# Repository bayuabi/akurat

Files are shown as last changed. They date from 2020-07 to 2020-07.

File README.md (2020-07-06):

# AKURAT
AKURAT stands for "Alat Ukur Kadar Air Tanah", an IoT based soil moisture sensor with ESP-32 inside. This project dedicated for soil
moisture data logging and then collected data can be analyzed for research purpose.

### Specifications :
- Wi-Fi based IoT
- OLED Display
- Solar panel energy harvesting
- 3500 mAh Lithium Ion battery
- Deep sleep enabled (for long time battery life)

### Further Specifications :
- LoRa/NB-IoT IoT protocols

Reach me on email (bayuabi31@gmail.com) for more informations.

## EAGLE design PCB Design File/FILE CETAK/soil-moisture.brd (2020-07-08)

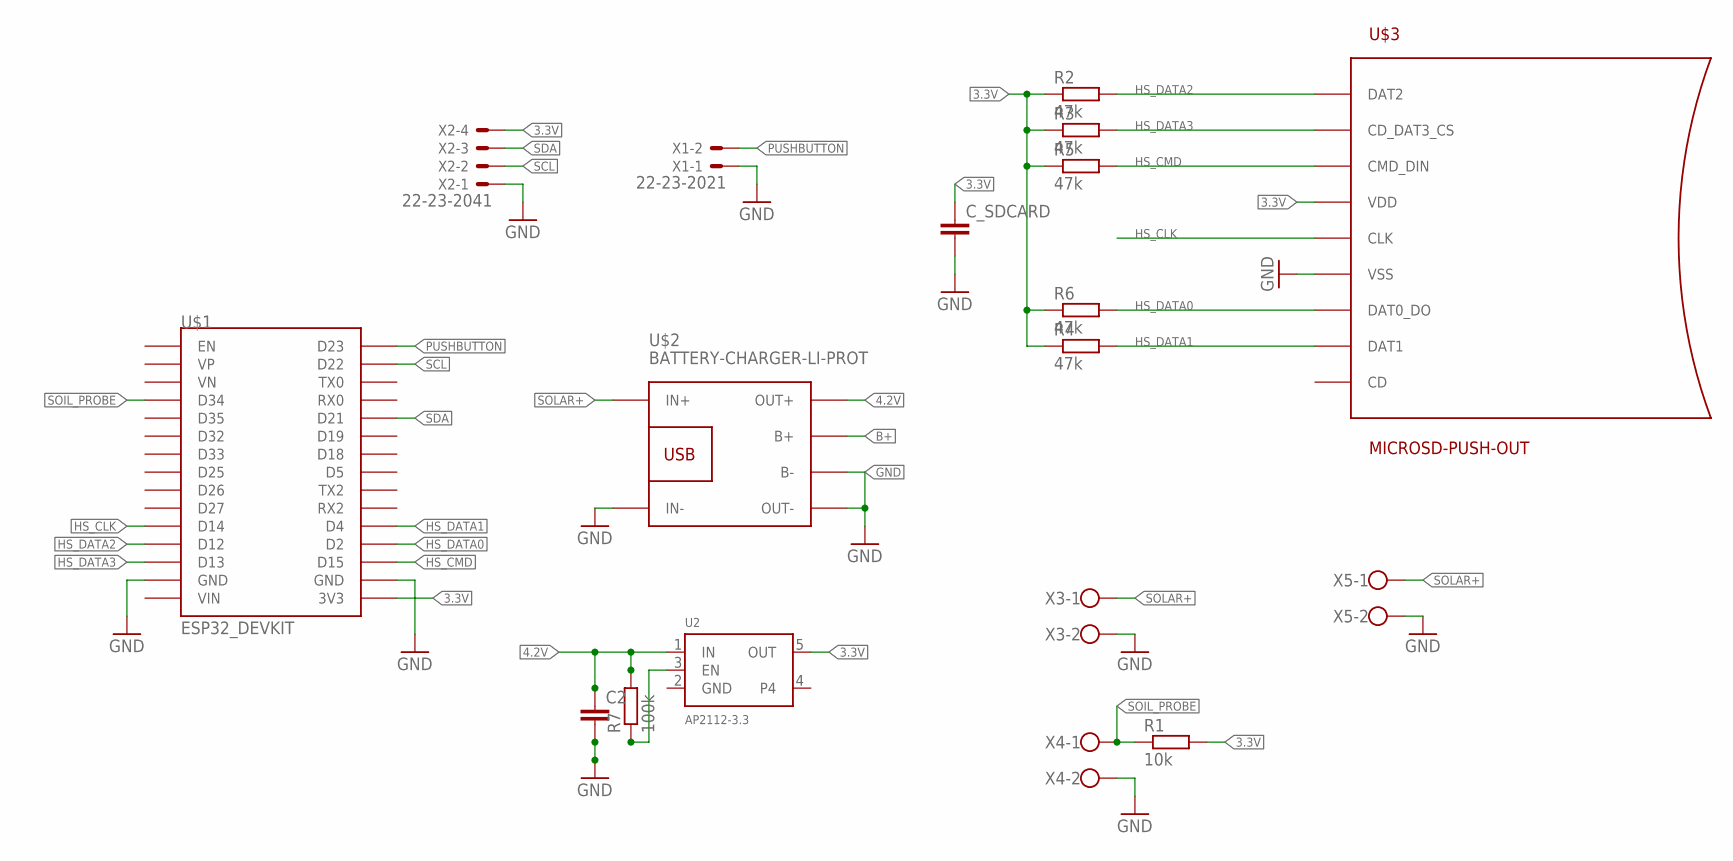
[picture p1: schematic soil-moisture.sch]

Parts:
C2: C-EUC0805; C0805
C_SDCARD: C-EUC0805; C0805
R1: 10k; R0805
R2, R3, R4, R5, R6: 47k; R0805
R7: 100k; R0805
U2: AP2112-3.3; SOT23-5
U$1: ESP32_DEVKIT
U$2: BATTERY-CHARGER-LI-PROT
U$3: MICROSD-PUSH-OUT
X1: 22-23-2021
X2: 22-23-2041
X3, X4, X5: W237-102

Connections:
3.3V: C_SDCARD.1, R1.2, R2.1, R3.1, R4.1, R5.1, R6.1, U2.5 (OUT), U$1.3V3, U$3.4 (VDD), X2.4
4.2V: C2.1, R7.2, U2.1 (IN), U$2.OUT+
B+: U$2.B+
GND: C2.2, C_SDCARD.2, U2.2 (GND), U$1.GND@1 (GND), U$1.GND@2 (GND), U$2.B-, U$2.IN-, U$2.OUT-, U$3.6 (VSS), U$3.G1 (VSS), U$3.G2 (VSS), U$3.G3 (VSS), U$3.G4 (VSS), X1.1, X2.1, X3.2, X4.2, X5.2
HS_CLK: U$1.D14, U$3.5 (CLK)
HS_CMD: R5.2, U$1.D15, U$3.3 (CMD_DIN)
HS_DATA0: R6.2, U$1.D2, U$3.7 (DAT0_DO)
HS_DATA1: R4.2, U$1.D4, U$3.8 (DAT1)
HS_DATA2: R2.2, U$1.D12, U$3.1 (DAT2)
HS_DATA3: R3.2, U$1.D13, U$3.2 (CD_DAT3_CS)
unnamed: R7.1, U2.3 (EN)
PUSHBUTTON: U$1.D23, X1.2
SCL: U$1.D22, X2.2
SDA: U$1.D21, X2.3
SOIL_PROBE: R1.1, U$1.D34, X4.1
SOLAR+: U$2.IN+, X3.1, X5.1

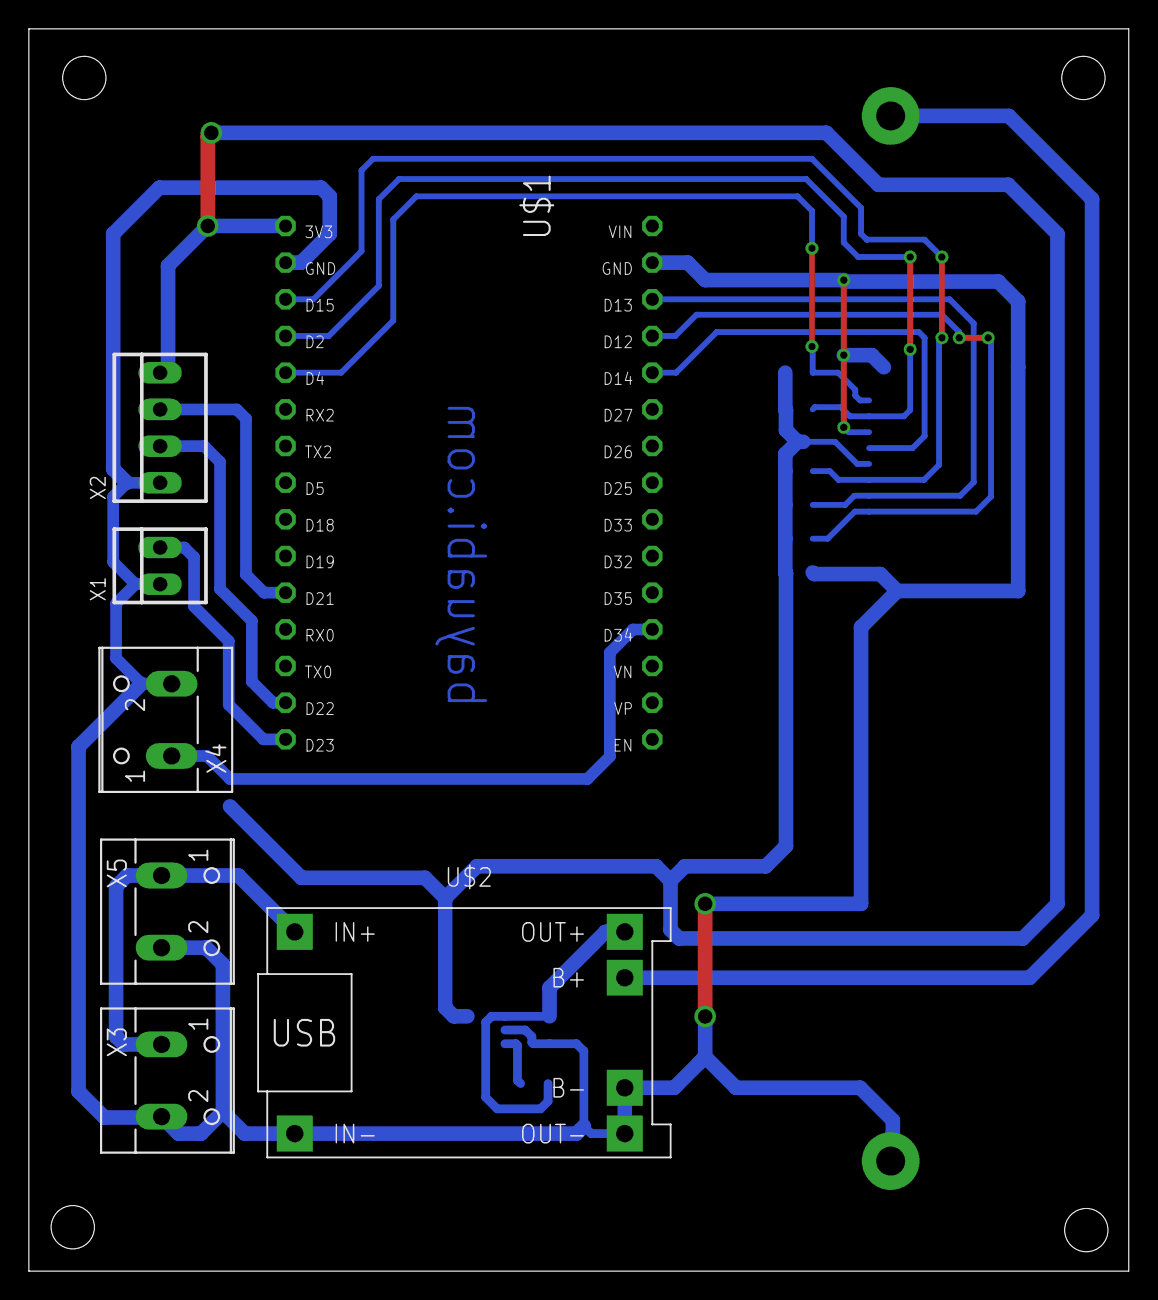
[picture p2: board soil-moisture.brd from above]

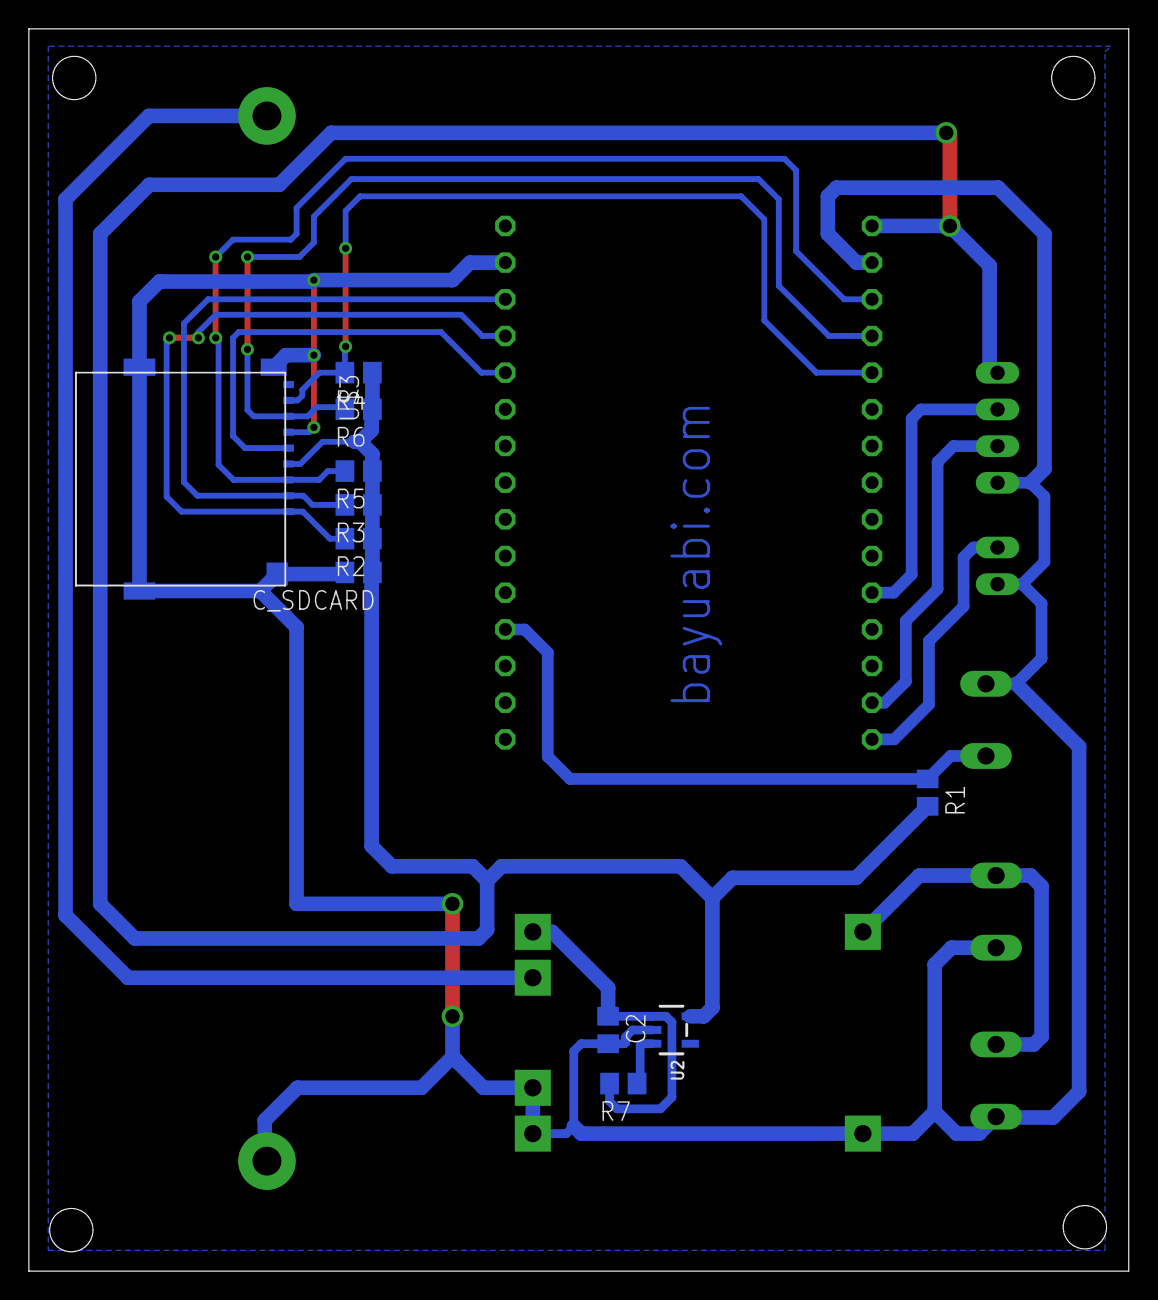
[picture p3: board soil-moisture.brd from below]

Board: 2 copper layers, 76.2 x 86.0 mm, 18 parts (11 on the bottom side), 15 nets.

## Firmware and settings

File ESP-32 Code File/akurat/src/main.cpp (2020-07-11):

#include <Arduino.h>
#include <WiFi.h>
#include <HTTPClient.h>
#include <WiFiClient.h>
#include <ESP_WiFiManager.h>
#include <Wire.h>
#include <Adafruit_GFX.h>
#include <Adafruit_SSD1306.h>

#define DEBUG true

#define SCREEN_WIDTH 128 
#define SCREEN_HEIGHT 64 

#define OLED_RESET     -1 
Adafruit_SSD1306 display(SCREEN_WIDTH, SCREEN_HEIGHT, &Wire, OLED_RESET);

String WIFI_SSID = "";
String WIFI_PASSWORD = "";

String MAIN_URL = "http://172.20.10.8/";
String SUBFOLDER_URL = "iot-dashboard/inputdata.php";

String CHIP_ID = "";

const char * API_KEY_TABLE[10] = {
                                  "miq3TdbIZP",
                                  "FDuzbCgPPb",
                                  "NqqRDCN52d",
                                  "QFsMgCkZsL",
                                  "lUpmcjKMeP",
                                  "F10NJIbkPf",
                                  "a1HQ8Gz6lM",
                                  "jPD9rmW5z4",
                                  "2vIt0XlQIQ",
                                  "ZoUBAoZ2uF"
                                 };

#define PUSHBUTTON_PIN  23
#define SOIL_PROBE_PIN  34

unsigned long startTime;
const uint16_t WIFIMANAGER_WAIT_TIME = 3000;
bool wifiSetting = false;

bool wifiInit(uint8_t timeout);
String getChipId();
bool sendData(int data);

void setup() {
  Serial.begin(115200);

  pinMode(PUSHBUTTON_PIN, INPUT_PULLUP);
  pinMode(SOIL_PROBE_PIN, INPUT);

  ESP_WiFiManager ESP_wifiManager("AutoConnectAP");
  ESP_wifiManager.setDebugOutput(true);
  ESP_wifiManager.setAPStaticIPConfig(IPAddress(192, 168, 100, 1), IPAddress(192, 168, 100, 1), IPAddress(255, 255, 255, 0));
  ESP_wifiManager.setMinimumSignalQuality(-1);
  ESP_wifiManager.setSTAStaticIPConfig(IPAddress(192, 168, 2, 114), IPAddress(192, 168, 2, 1), IPAddress(255, 255, 255, 0),
                                       IPAddress(192, 168, 2, 1), IPAddress(8, 8, 8, 8));

  startTime = millis();
  while(millis() - startTime <= WIFIMANAGER_WAIT_TIME){
    if(!digitalRead(PUSHBUTTON_PIN)){
      wifiSetting = true;
    }
    else{
      wifiSetting = false;
    }
  }

  if(wifiSetting){
    String AP_SSID = "AKURAT";
    String AP_PASS = "12345678";
    ESP_wifiManager.autoConnect(AP_SSID.c_str(), AP_PASS.c_str());
  }

  WIFI_SSID = ESP_wifiManager.getStoredWiFiSSID();
  WIFI_PASSWORD = ESP_wifiManager.getStoredWiFiPass();

  wifiInit(10);

  CHIP_ID = getChipId();
  if(DEBUG) Serial.println(CHIP_ID);

  if(!display.begin(SSD1306_SWITCHCAPVCC, 0x3C)) { 
    if(DEBUG) Serial.println(F("SSD1306 allocation failed"));
  }

  display.display();
}

void loop() {
  sendData(random(0,100));
  delay(1000);
}

bool wifiInit(uint8_t timeout){
  WiFi.begin(WIFI_SSID.c_str(), WIFI_PASSWORD.c_str());
  for(int i=0; i<timeout; i++){
    if(WiFi.status() == WL_CONNECTED){
      if(DEBUG) Serial.println("WIFI CONNECTED");

      return true;
    } 
    delay(1000);
  }
  if(DEBUG) Serial.println("FAIL CONNECT TO WIFI");
  return false;
}

String getChipId(){
  uint64_t ESP_CHIP_ID = ESP.getEfuseMac();
  char chipIdBuf[100];
  sprintf(chipIdBuf, "%x", ESP_CHIP_ID);
  String CHIP_ID = chipIdBuf;
  CHIP_ID.toUpperCase();

  return CHIP_ID;
}

bool sendData(int data){
  if(WiFi.status() == WL_CONNECTED){
    HTTPClient http;

    String URL = MAIN_URL + SUBFOLDER_URL;

    http.begin(URL);
    http.addHeader("Content-Type", "application/x-www-form-urlencoded");

    char bodyMessage[200];
    sprintf(bodyMessage, "api_key=%s&node_id=%s&soil=%d", API_KEY_TABLE[random(0,9)], CHIP_ID, data);

    int httpResponse = http.POST(bodyMessage);
    if(DEBUG) Serial.print("HTTP Response: "); Serial.println(httpResponse);
    http.end();
  }
}

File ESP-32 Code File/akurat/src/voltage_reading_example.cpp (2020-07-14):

/*void setup() {
  Serial.begin(115200);
}

void loop() {
  uint16_t adc = analogRead(32);
  Serial.println(adc);
  Serial.println(linierCalc(adc, 0.0018493150684932, 0.2808904109589));
  delay(1000);
}

float linierCalc(uint16_t adc, float slope, float intercept){
  return ((float)adc * slope) + intercept;
}*/

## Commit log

2020-07-06 add pcb design file
    [soil-moisture.brd, soil-moisture.sch]
2020-07-06 add new folder
    [soil-moisture.brd, soil-moisture.sch]
2020-07-08 add board eagle 7
    [soil-moisture.brd, soil-moisture.sch]

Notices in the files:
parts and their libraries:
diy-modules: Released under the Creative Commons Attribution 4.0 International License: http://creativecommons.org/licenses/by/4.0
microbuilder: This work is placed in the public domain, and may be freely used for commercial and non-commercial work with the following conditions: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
